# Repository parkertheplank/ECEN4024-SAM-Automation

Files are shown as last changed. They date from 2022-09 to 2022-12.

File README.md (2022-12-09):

# ECEN4024-SAM-Automation

## A fully functional program which automates the Super Air Meter, which is a quality control device for concrete, by measuring air volume and distribution. 

## Navigating the files

This repo has many folders. For the critical files and folders there will be additional READMEs. Those will be the most important to read. Here's a short explanation of the folders and files present.

 * masterSAM - The most important folder. This holds the fully functional automated program for the Arduino c/c++ IDE.
 * SAM-KICAD-Schematic - This is an electrical schematic of our automated device. 
 * SAM-MATLAB-Transducer-Calibration - Code we used to make lines of best fit to match the SAM gauge psi readings
 * SAM-Previous teams LCD - LCD code from team previous to Fall2022
 * SAM-Unit Test an assortment of unit tests we used before transitioning to our main file.

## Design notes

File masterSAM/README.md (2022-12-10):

# masterSAM

## Arduino IDE C/C++ Program which runs our device which automates the Super Air Meter Test

## Navigating the files
There are six different .ino files in this folder
* masterSAM.ino - The main file containing the core program and control loop. Open this file and the others should populate as tabs
* air.ino - Functions for air bleeding, pressurization, and air reading 
* testFunctions.ino - Several test functions that can replace mainSAM() in loop() to test various functions
* userInterface.ino - Functions for the buttons, data storage and LCD screen
* mechanical.ino - Functions for the tilt mechanism and vibrator
* water.ino - Functions for the setup and control of the water pump, intake, and outake valves.

## Running The Code
These six files must be located within a folder named 'masterSam' open masterSam.ino in the arduino IDE and other files should populate as tabs. Compile and download the masterSAM file. 

On the device itself, turn on battery power then plug USB cable in to download new changes in code. Then unplug before you turn off the switch. If you don't do it in this order it can bug out the LCD screen but no serious issue. Otherwise just turn on power switch and press start.

## Editing the Code
Always fetch origin and pull any changes before edititing, and/or create your own branch

## Outstanding Issues/Bugs
Recommendations
* Consider using micros()/millis() or some other timing module instead of the vanilla delay(). Delay() is blocking. Also millis() could be useful in measuring update rate of psi by data dumping sys time paired with psi reading and average
* Play with different lines of best fit from our MATLAB data. Implement these equations in the airRead() function
* Implement tare button - Could be an interupt which simply sets an offset float to current air reading. airRead() then would subtract this offset from equation. We were able to get .01 psi accuracy but offset error would occur between days.
* Implement some sort of reset function which will tilt back and depressurize

Bugs
* Both interupts can be triggered by relays causing noise in wire. Code currently handles this but could cause issues

Issues
* Data storage functions and variables are present but not fully implemented
* Several of the test functions require more changes to the program than simply swapping them for mainSAM() or are incomplete
* Issues could occur if proram is stopped (power switch turned off) midway through program. Some way of handling this case and running a reset funciton is needed.

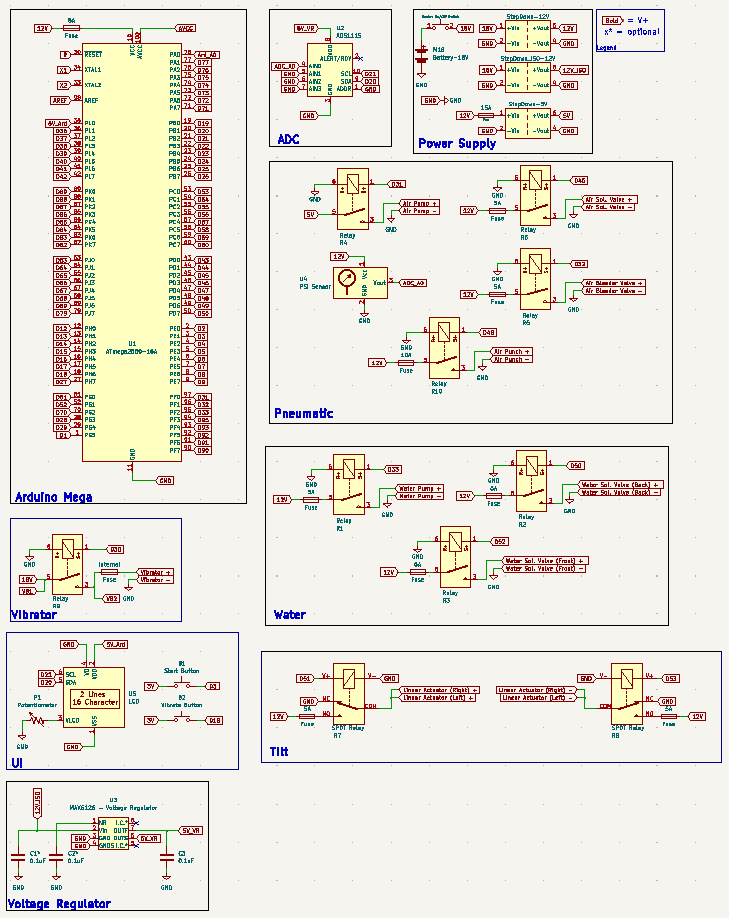
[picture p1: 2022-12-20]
ASAM_Schematic_Updated/ASAM_Schematic_Updated.PNG

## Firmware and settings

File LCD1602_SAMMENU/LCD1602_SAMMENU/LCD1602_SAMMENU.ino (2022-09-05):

#include <LiquidCrystal.h>
#include "LiquidMenu.h"
#include <EEPROM.h>
#include "Button.h"

// Pin mapping for the display
LiquidCrystal lcd(12,11,5,4,3,2);

// Button objects instantiation
Button up(8, true);//previous screen
Button down(9, true);//next screen
Button select(10, true);
Button enter(7, true);

// The analog reading sample period in seconds.
// It is later overwritten by it's EEPROM value.
unsigned short sample_period = 1;

int i=1;

int keyVal;
int P1avg=0;
int P2avg=0;
int P3avg=0;
int P4avg=0;
int P1avgtest=0;
int P2avgtest=0;
int P3avgtest=0;
int P4avgtest=0;

enum FunctionTypes { ENTER = 1,BACK = 2,};

LiquidLine KEYVAL(0,0,keyVal);

LiquidLine goback_main(13,1,"BA");
LiquidLine goback_calib(13,1,"BA");
LiquidLine goback_view(13,1,"BA");
LiquidLine goback_start(13,0, "BA");

//LiquidLine enter_start(13,0,"EN");

LiquidLine test(0, 0, "1.TEST ");
LiquidLine calib(0, 1, "2.CALIB");
LiquidLine reset(8, 0, "3.RESET");
LiquidLine light(8, 1, "4.LIGHT");
LiquidScreen screen_main(test, calib, reset, light);
LiquidMenu menu_main(lcd, screen_main);

LiquidLine sam(0, 0, "->SAM");
LiquidLine typeb(0, 1, "->TYPEB");
LiquidScreen screen_test(sam, typeb, goback_main);
LiquidMenu menu_test(lcd, screen_test);

LiquidLine start(0, 0, "->START:");
LiquidLine view(0, 1, "->VIEW:");
LiquidScreen screen_calib(start,view, goback_main);
LiquidMenu menu_calib(lcd, screen_calib);

char*  showhint="PRESS";
LiquidLine hint(0,1,showhint);
LiquidScreen screen_hint( hint,  KEYVAL);
LiquidMenu menu_hint(lcd, screen_hint);

LiquidLine cnfrm(0, 0, "->CNFRM:");
LiquidLine cancl(0, 1, "->CANCL:");
LiquidScreen screen_reset(cnfrm,cancl, goback_main);
LiquidMenu menu_reset(lcd, screen_reset);

LiquidLine off(0, 0, "->OFF:");
LiquidLine on(0, 1, "->ON:");
LiquidScreen screen_light1(off,on, goback_main);
LiquidLine Press(0, 0, "->PRESS:");
LiquidLine T20min(0, 1, "->20MIN:");
LiquidScreen screen_light2(Press,T20min, goback_main);
LiquidLine T5min(0, 0, "->5MIN:");
LiquidLine T1min(0, 1, "->1MIN:");
LiquidScreen screen_light3(T5min,T1min, goback_main);
LiquidMenu menu_light(lcd, screen_light1, screen_light2, screen_light3);

LiquidLine p1a(0, 0, "->P1-A:",P1avg);
LiquidLine p2a(0, 1, "->P2-A:",P2avg);
LiquidScreen screen_view1(p1a,p2a, goback_calib);
LiquidLine p3a(0, 0, "->P3-A:",P3avg);
LiquidLine p4a(0, 1, "->P4-A:",P4avg);
LiquidScreen screen_view2(p3a,p4a, goback_calib);
LiquidLine vtop(0, 0, "->VTOP:");
LiquidLine vbowl(0, 1, "->VBOWL:");
LiquidScreen screen_view3(vtop,vbowl, goback_calib);
LiquidMenu menu_view(lcd, screen_view1, screen_view2, screen_view3);

LiquidLine recal(0, 0, "->RECAL:");
LiquidScreen screen_vbowl(recal, goback_view);
LiquidMenu menu_vbowl(lcd, screen_vbowl);

LiquidSystem menu_system(menu_main, menu_test, menu_calib,menu_reset);

void buttonsCheck() {
  if (up.check() == LOW) {
    menu_system.previous_screen();
  }
  if (down.check() == LOW) {
    menu_system.next_screen();
  }
   if (select.check() == LOW) {
   menu_system.switch_focus();
  }
  if (enter.check() == LOW) {
    menu_system.call_function(ENTER);
  }
  return;
}

void screenshowcontrol(){
   static unsigned long lastMillis_sample01 = 0;
   keyVal= analogRead(A0);
   if (millis() - lastMillis_sample01 > (sample_period * 200)) {
      lastMillis_sample01 = millis(); 
      menu_system.update();}
   return;
}

void gobackto_menu_main() {
  menu_system.change_menu(menu_main);
  return;
}
void goto_menu_test() {
  menu_system.change_menu(menu_test);
  return;
}
void goto_menu_calib() {
  menu_system.change_menu(menu_calib);
  return;
}
void goto_menu_reset() {
  menu_system.change_menu(menu_reset);
  return;
}
void goto_menu_light() {
  menu_system.change_menu(menu_light);
  return;
}
void goto_menu_view() {
  menu_system.change_menu(menu_view);
  return;
}
void goto_menu_vbowl() {
  menu_system.change_menu(menu_vbowl);
  return;
}

void goto_menu_start(){ 
 while(enter.check() == HIGH){
    menu_system.change_menu(menu_hint);
    long lastMillis_test =millis();
    int t=0;
     while (t<8800){
        t=millis()-lastMillis_test;
       // keyVal= analogRead(A0);
        if (t < 800) {  
          showhint=(char*)"          PRESS/"; 
          screenshowcontrol();}
        if (t > 800 && t< 1600) { 
          showhint=(char*)"          ENTER/"; 
          screenshowcontrol();}
        if (t > 1600 && t< 2400) { 
          showhint=(char*)"             TO/"; 
          screenshowcontrol();}
        if (t > 2400 && t< 3200) { 
          showhint=(char*)"         BEGAIN/";
         screenshowcontrol();}
        if (t > 3200 && t< 4000) { 
          showhint=(char*)"            SAM/";
          screenshowcontrol();}
        if (t > 4000 && t< 4800) { 
          showhint=(char*)"          CALIB/";
          screenshowcontrol();}
        if (t > 4800 && t< 5600) { 
          showhint=(char*)"             OR/";
         screenshowcontrol();}
        if (t > 5600 && t< 6400) { 
          showhint=(char*)"           HOLD/";
          screenshowcontrol();}
        if (t > 6400 && t< 7200) { 
          showhint=(char*)"           MENU/";
          screenshowcontrol();}
        if (t > 7200 && t< 8000) { 
          showhint=(char*)"             TO/";
          screenshowcontrol();}
        if (t > 8000 && t< 8800) {
          showhint=(char*)"           ABORT";
          screenshowcontrol();}
        if (enter.check() == LOW) {goto_menu_startEnter(); return;}}}
 }

void goto_menu_startEnter(){
  goto_menu_apply1450();
  goto_menu_startEnterEnter();
  return;
}

void goto_menu_apply1450(){ 
  while(enter.check() == HIGH){   
    menu_system.change_menu(menu_hint);
    long lastMillis_test =millis();
    int t=0;
     while (t<4800){
        t=millis()-lastMillis_test;
        if (t < 800) {  
          showhint=(char*)"          APPLY/"; 
          screenshowcontrol();}
        if (t > 800 && t< 1600) { 
          showhint=(char*)"          14.50/"; 
          screenshowcontrol();}
        if (t > 1600 && t< 2400) { 
          showhint=(char*)"            PSI/"; 
          screenshowcontrol();}
        if (t > 2400 && t< 3200) { 
          showhint=(char*)"           THEN/";
          screenshowcontrol();}
        if (t > 3200 && t< 4000) { 
          showhint=(char*)"          PRESS/";
          screenshowcontrol();}
        if (t > 4000 && t< 4800) { 
          showhint=(char*)"           ENTER";
          screenshowcontrol();}
        if (enter.check()==LOW){return;}
 }}}
 
void goto_menu_startEnterEnter(){ 
  menu_system.change_menu(menu_hint); 
  /****************************************************************************************************
   * capture five measurements while flashing “READ”
  *****************************************************************************************************/
  long lastMillis_test =millis();
  int t=0;
  while (t<7100){ 
    t=millis()-lastMillis_test;
    if (t < 5000) {
      int a=t/400;
      if ((a%2)!=0){  
        showhint=(char*)"            READ";  
        screenshowcontrol();}
        else {
          showhint=(char*)" ";  
          screenshowcontrol();}}
     if (t > 5000 && t< 7000) { 
         if(keyVal>800){
            showhint=(char*)"      NOT STABLE"; 
            screenshowcontrol();}
         else{
          if(keyVal>200 && keyVal<600){               
              showhint=(char*)"              OK"; 
              screenshowcontrol();}
          if(keyVal<200){
              showhint=(char*)"             LOW"; 
              screenshowcontrol();}
           if(keyVal>600 && keyVal<800){
              showhint=(char*)"            HIGH"; 
              screenshowcontrol();}
            }}
     if (t > 7000 && t <7100){
         if(keyVal<200 || keyVal>600 ){goto_menu_startEnter(); return;}
         if(keyVal>200 && keyVal<600){goto_menu_startEEOK();return;}
}}}

void goto_menu_startEEOK(){
    goto_menu_holdhint();
    goto_menu_holdcount();
    goto_menu_startEEEnter();
    return;
 }

void goto_menu_holdhint(){  
  while(enter.check()==HIGH){
    menu_system.change_menu(menu_hint);
    long lastMillis_test =millis();
    int t=0;
    while (t<4000){
        t=millis()-lastMillis_test;
        if (t < 800) { 
              showhint=(char*)"           HOLD/"; 
              screenshowcontrol();}
        if (t > 800 && t< 1600) { 
              showhint=(char*)"          LEVER/"; 
              screenshowcontrol();}
        if (t > 1600 && t< 2400) { 
              showhint=(char*)"           THEN/";
              screenshowcontrol();}
        if (t > 2400 && t< 3200) { 
               showhint=(char*)"          PRESS/";
              screenshowcontrol();}
        if (t > 3200 && t< 4000) { 
              showhint=(char*)"           ENTER";
              screenshowcontrol();}
        if (enter.check() == LOW) {
              return;}
 }}}

void goto_menu_holdhithint(){  
  while(enter.check()==HIGH){
    menu_system.change_menu(menu_hint);
    long lastMillis_test =millis();
    int t=0;
    while (t<4800){
        t=millis()-lastMillis_test;
        if (t < 800) { 
              showhint=(char*)"           HOLD/"; 
              screenshowcontrol();}
        if (t > 800 && t< 1600) { 
              showhint=(char*)"          LEVER/"; 
              screenshowcontrol();}
        if (t > 1600 && t< 2400) { 
              showhint=(char*)"            HIT/";
              screenshowcontrol();}
        if (t > 2400 && t< 3200) { 
              showhint=(char*)"           THEN/";
              screenshowcontrol();}
        if (t > 3200 && t< 4000) { 
              showhint=(char*)"          PRESS/";
              screenshowcontrol();}
        if (t > 4000 && t< 4800) { 
              showhint=(char*)"           ENTER";
              screenshowcontrol();}
        if (enter.check() == LOW) {
              return;}
 }}}

void goto_menu_holdcount(){
    menu_system.change_menu(menu_hint);
    long lastMillis_test =millis();
    int t=0;
    while (t<8100){
        t=millis()-lastMillis_test; 
        if ( t< 800) { 
              showhint=(char*)"           HOLD9";
              screenshowcontrol();}
        if (t > 800 && t< 1600) { 
              showhint=(char*)"           HOLD8";
              screenshowcontrol();}
        if (t > 1600 && t< 2400) { 
              showhint=(char*)"           HOLD7";
              screenshowcontrol();}
        if (t > 2400 && t< 3200) { 
              showhint=(char*)"           HOLD6";
              screenshowcontrol();}
        if (t > 3200 && t< 4000) { 
              showhint=(char*)"           HOLD5";
              screenshowcontrol();}
        if (t > 4000 && t< 4800) { 
              showhint=(char*)"           HOLD4";
              screenshowcontrol();}
        if (t > 4800 && t< 5600) { 
              showhint=(char*)"           HOLD3";
              screenshowcontrol();}
        if (t > 5600 && t< 6400) { 
              showhint=(char*)"           HOLD2";
              screenshowcontrol();}
        if (t > 6400 && t< 7200) { 
              showhint=(char*)"           HOLD1";
              screenshowcontrol();}
        if (t > 7200 && t< 8000) { 
              showhint=(char*)"           HOLD0";
              screenshowcontrol();}
}}

void goto_menu_startEEEnter(){
    goto_menu_readhint();
    if(keyVal>800){goto_Error();return;}
    else{
        P1avgtest=keyVal;
        goto_menu_OKhint();
        goto_menu_startEEEEnter();
        return;
        }
}

void goto_menu_readhint(){
  menu_system.change_menu(menu_hint);
  long lastMillis_test =millis();
  int t=0;
  while (t<5000){ 
    t=millis()-lastMillis_test;
    int a=t/400;
    if ((a%2)!=0){  
        showhint=(char*)"            READ";  
        screenshowcontrol();}
    else {
        showhint=(char*)" ";  
        screenshowcontrol();}}}

void goto_menu_OKhint(){
  menu_system.change_menu(menu_hint);
  long lastMillis_test =millis();
  int t=0;
  while (t<2000){ 
    t=millis()-lastMillis_test;
    showhint=(char*)"              OK";  
    screenshowcontrol();
   }
}

void goto_Error(){ 
  while(enter.check() == HIGH){   
    menu_system.change_menu(menu_hint);
    long lastMillis_test =millis();
    int t=0;
    while (t<5600){
        t=millis()-lastMillis_test;
        if (t < 800) {  
          showhint=(char*)"          ERROR/"; 
          screenshowcontrol();}
        if (t > 800 && t< 1600) { 
          showhint=(char*)"            NOT/"; 
          screenshowcontrol();}
        if (t > 1600 && t< 2400) { 
          showhint=(char*)"         STABLE/"; 
          screenshowcontrol();}
        if (t > 2400 && t< 3200) { 
          showhint=(char*)"          PRESS/";
          screenshowcontrol();}
        if (t > 3200 && t< 4000) { 
          showhint=(char*)"          ENTER/";
         screenshowcontrol();}
        if (t > 4000 && t< 4800) { 
          showhint=(char*)"             TO/";
          screenshowcontrol();}
        if (t > 4800 && t< 5600) { 
          showhint=(char*)"            EXIT";
          screenshowcontrol();}
        if (enter.check() == LOW) {gobackto_menu_main();return;}
 }}}

void goto_menu_startEEEEnter(){
  goto_menu_apply3000();
  goto_menu_P2Enter();
  return;
}

void goto_menu_apply3000(){ 
  while(enter.check() == HIGH){   
    menu_system.change_menu(menu_hint);
    long lastMillis_test =millis();
    int t=0;
     while (t<4800){
       // keyVal= analogRead(A0);
        t=millis()-lastMillis_test;
        if (t < 800) {  
          showhint=(char*)"          APPLY/"; 
          screenshowcontrol();}
        if (t > 800 && t< 1600) { 
          showhint=(char*)"          30.00/"; 
         screenshowcontrol();}
        if (t > 1600 && t< 2400) { 
          showhint=(char*)"            PSI/"; 
          screenshowcontrol();}
        if (t > 2400 && t< 3200) { 
          showhint=(char*)"           THEN/";
          screenshowcontrol();}
        if (t > 3200 && t< 4000) { 
          showhint=(char*)"          PRESS/";
         screenshowcontrol();}
        if (t > 4000 && t< 4800) { 
          showhint=(char*)"           ENTER";
          screenshowcontrol();}
        if (enter.check() == LOW) { return;}
 }}}

void goto_menu_P2Enter(){ 
  menu_system.change_menu(menu_hint); 
  /****************************************************************************************************
   * capture five measurements while flashing “READ”
  *****************************************************************************************************/
  long lastMillis_test =millis();
  int t=0;
  while (t<7100){ 
    t=millis()-lastMillis_test;
    if (t < 5000) {
      int a=t/400;
      if ((a%2)!=0){  
        showhint=(char*)"            READ";  
        screenshowcontrol();}
      else {
        showhint=(char*)" ";  
        screenshowcontrol();}}
    if (t > 5000 && t< 7000) { 
         if(keyVal>200 && keyVal<600){               
            showhint=(char*)"              OK"; 
            screenshowcontrol();}
         if(keyVal<200){
            showhint=(char*)"             LOW"; 
            screenshowcontrol();}
         if(keyVal>600 && keyVal<800){
            showhint=(char*)"            HIGH"; 
            screenshowcontrol();}
            }
     if (t > 7000 && t <7100){
         if(keyVal<200 || keyVal>600){goto_menu_startEEEEnter();return;}
         if(keyVal>200 && keyVal<600){goto_menu_P2EOK();return;}
}}}

void goto_menu_P2EOK(){
  goto_menu_holdhint();
  goto_menu_holdcount();
  goto_menu_P2EEnter();
  return;
}

void goto_menu_P2EEnter(){
  goto_menu_readhint();
  if(keyVal>800){goto_Error();return;}
  else{
        P2avgtest=keyVal;
        goto_menu_OKhint();
        goto_menu_P2EEEnter();return;
        }
}

void goto_menu_P2EEEnter(){
  goto_menu_apply4500();
  goto_menu_P3Enter();
  return;
}
         
void goto_menu_apply4500(){
 while(enter.check() == HIGH){   
    menu_system.change_menu(menu_hint);
    long lastMillis_test =millis();
    int t=0;
     while (t<4800){
        t=millis()-lastMillis_test;
        if (t < 800) {  
          showhint=(char*)"          APPLY/"; 
          screenshowcontrol();}
        if (t > 800 && t< 1600) { 
          showhint=(char*)"          45.00/"; 
          screenshowcontrol();}
        if (t > 1600 && t< 2400) { 
          showhint=(char*)"            PSI/"; 
          screenshowcontrol();}
        if (t > 2400 && t< 3200) { 
          showhint=(char*)"           THEN/";
          screenshowcontrol();}
        if (t > 3200 && t< 4000) { 
          showhint=(char*)"          PRESS/";
          screenshowcontrol();}
        if (t > 4000 && t< 4800) { 
          showhint=(char*)"           ENTER";
          screenshowcontrol();}
        if (enter.check() == LOW) {return;}
 }}}

 void goto_menu_P3Enter(){
  menu_system.change_menu(menu_hint); 
  /****************************************************************************************************
   * capture five measurements while flashing “READ”
  *****************************************************************************************************/
  long lastMillis_test =millis();
  int t=0;
  while (t<7100){ 
    t=millis()-lastMillis_test;
    if (t < 5000) {
      int a=t/400;
      if ((a%2)!=0){  
        showhint=(char*)"            READ";  
        screenshowcontrol();}
      else {
        showhint=(char*)" ";  
        screenshowcontrol();}}
    if (t > 5000 && t< 7000) { 
         if(keyVal>200 && keyVal<600){               
            showhint=(char*)"              OK"; 
            screenshowcontrol();}
         if(keyVal<200){
            showhint=(char*)"             LOW"; 
            screenshowcontrol();}
         if(keyVal>600 && keyVal<800){
            showhint=(char*)"            HIGH"; 
            screenshowcontrol();}
            }
     if (t > 7000 && t <7100){
         if(keyVal<200 || keyVal>600){goto_menu_P2EEEnter();return;}
         if(keyVal>200 && keyVal<600){goto_menu_P3EOK();return;}
         }}}

void goto_menu_P3EOK(){
  goto_menu_holdhint();
  goto_menu_holdcount();
  goto_menu_P3EEnter();
  return;
}

void goto_menu_P3EEnter(){
    goto_menu_readhint();
    if(keyVal>800){goto_Error();return;}
    else{
        P3avgtest=keyVal;
        // This is where the user removes the lid and places a calibration can in the chamber.
        goto_menu_OKhint();
        goto_menu_P3EEEnter();
        return;
        }
    }

void goto_menu_P3EEEnter(){
  // This is where the user removes the lid and places a calibration can in the chamber.
   while(enter.check() == HIGH){   
    menu_system.change_menu(menu_hint);
    long lastMillis_test =millis();
    int t=0;
     while (t<5600){
        t=millis()-lastMillis_test;
        if (t < 800) {  
          showhint=(char*)"          PURGE/"; 
          screenshowcontrol();}
        if (t > 800 && t< 1600) { 
          showhint=(char*)"            ADD/"; 
          screenshowcontrol();}
        if (t > 1600 && t< 2400) { 
          showhint=(char*)"            ONE/"; 
          screenshowcontrol();}
        if (t > 2400 && t< 3200) { 
          showhint=(char*)"            CAN/";
          screenshowcontrol();}
        if (t > 3200 && t< 4000) { 
          showhint=(char*)"           THEN/";
          screenshowcontrol();}
        if (t > 4000 && t< 4800) { 
          showhint=(char*)"           PRESS";
          screenshowcontrol();}
        if (t > 4800 && t< 5600) { 
          showhint=(char*)"           ENTER";
          screenshowcontrol();}
        if (enter.check() == LOW) {goto_menu_P3EEEEnter();return;/*if select button has been poshed,then stop showing the hint.*/}
 }}}

void goto_menu_P3EEEEnter(){
   goto_menu_apply1450();
   goto_menu_P4Enter();
   return;
 }

void goto_menu_P4Enter(){
  menu_system.change_menu(menu_hint); 
  /****************************************************************************************************
   * capture five measurements while flashing “READ”
  *****************************************************************************************************/
  long lastMillis_test =millis();
  int t=0;
  while (t<7100){ 
    t=millis()-lastMillis_test;
    if (t < 5000) {
      int a=t/400;
      if ((a%2)!=0){  
        showhint=(char*)"            READ";  
        screenshowcontrol();}
      else {
        showhint=(char*)" ";  
        screenshowcontrol();}}
    if (t > 5000 && t< 7000) { 
         if(keyVal>200 && keyVal<600){               
            showhint=(char*)"              OK"; 
            screenshowcontrol();}
         if(keyVal<200){
            showhint=(char*)"             LOW"; 
            screenshowcontrol();}
         if(keyVal>600 && keyVal<800){
            showhint=(char*)"            HIGH"; 
            screenshowcontrol();}
            }
     if (t > 7000 && t <7100){
         if(keyVal<200 || keyVal>600){goto_menu_P3EEEEnter();return;}
         if(keyVal>200 && keyVal<600){goto_menu_P4EOK();return;}
}}}

void goto_menu_P4EOK(){
  goto_menu_holdhint();
  goto_menu_holdcount();
  goto_menu_P4EEnter();
  return;
}

void goto_menu_P4EEnter(){
  goto_menu_readhint();
  if(keyVal>800){goto_Error();return;}
  else{
        P4avgtest=keyVal;
        // PressCorr = 7.51 – P4avg 
        // Note: This finds the correction to the equilibrium pressure to force meter to read 4.9% air +/-0.1% with a Pro Cali Can
        goto_menu_OKhint();
        goto_menu_P4EEEnter();return;}
}
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
void loop() {
  buttonsCheck();
  keyVal= analogRead(A0);
  Serial.print("keyVal:");
  Serial.println(keyVal);
  screenshowcontrol();}

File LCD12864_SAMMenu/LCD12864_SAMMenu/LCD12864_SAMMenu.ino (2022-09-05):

/*

  Menu.pde
  
  Simple Menu Selection

  >>> Before compiling: Please remove comment from the constructor of the 
  >>> connected graphics display (see below).
  
  Universal 8bit Graphics Library, https://github.com/olikraus/u8glib/
  
  Copyright (c) 2012, olikraus@gmail.com
  All rights reserved.

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
  THIS SOFTWARE IS PROVIDED BY THE COPYRIGHT HOLDERS AND 
  CONTRIBUTORS "AS IS" AND ANY EXPRESS OR IMPLIED WARRANTIES, 
  INCLUDING, BUT NOT LIMITED TO, THE IMPLIED WARRANTIES OF 
  MERCHANTABILITY AND FITNESS FOR A PARTICULAR PURPOSE ARE 
  DISCLAIMED. IN NO EVENT SHALL THE COPYRIGHT HOLDER OR 
  CONTRIBUTORS BE LIABLE FOR ANY DIRECT, INDIRECT, INCIDENTAL, 
  SPECIAL, EXEMPLARY, OR CONSEQUENTIAL DAMAGES (INCLUDING, BUT 
  NOT LIMITED TO, PROCUREMENT OF SUBSTITUTE GOODS OR SERVICES; 
  LOSS OF USE, DATA, OR PROFITS; OR BUSINESS INTERRUPTION) HOWEVER 
  CAUSED AND ON ANY THEORY OF LIABILITY, WHETHER IN CONTRACT, 
  STRICT LIABILITY, OR TORT (INCLUDING NEGLIGENCE OR OTHERWISE) 
  ARISING IN ANY WAY OUT OF THE USE OF THIS SOFTWARE, EVEN IF 
  ADVISED OF THE POSSIBILITY OF SUCH DAMAGE.  
  

*/


#include "U8glib.h"
#include "Button.h"
#include <stdio.h>

U8GLIB_KS0108_128 u8g(8, 9, 10, 11, 4, 5, 6, 7, 18, 14, 15, 17, 16); 		// 8Bit Com: D0..D7: 8,9,10,11,4,5,6,7 en=18, cs1=14, cs2=15,di=17,rw=16

float error = 5.00;
float minval = 13.00;
float maxval = 50.00;
float Vc = 1;
float Vbowl = 1;
float Presscorr = 1.00;

Button up(22, true);//previous screen
Button down(26, true);//next screen
Button enter(30, true);
Button back(34, true);

float measure[5];
float meas_error[5];
float P1avg,P2avg,P3avg,P4avg;
char *PoiP1avg = "####";
char *PoiP2avg = "####";
char *PoiP3avg = "####";
char *PoiP4avg = "####";
char strP1avg[10],strP2avg[10], strP3avg[10], strP4avg[10];//item number must be 10, otherwise there'll be garbled after transfer into string
float P1meas, P2meas, P3meas, P4meas, P5meas, P6meas;
char strP1meas[10], strP2meas[10], strP3meas[10], strP4meas[10], strP5meas[10], strP6meas[10];
float air;
char strair[10];
char *Poiair = "####";
float air_T;
char strair_T[10];
char *Poiair_T = "####";
float SAM;
char strSAM[10];
char *PoiSAM = "####";
float P1measmod;
float pressure;
char strpressure[10];
char *Poipressure;


char *menu_main[6] = { "1.TEST ", "2.CALIB", "3.RESET", "4.LIGHT","","Zero"};
char *menu_test[2] = {"1.SAM", "2.TYPEB"};
char *menu_calib[2] = {"1.START", "2.VIEW"};
char *menu_reset[2] = {"1.CNFRM", "2.CANCL"};
char *menu_light[6] = {"OFF", "ON", "PRESS", "20MIN", "5MIN", "1MIN"};
char *menu_view[10] = {"P1-A:", "P2-A:", "P3-A:", "P4-A:", "VTOP", "VBOWL",PoiP1avg,PoiP2avg,PoiP3avg,PoiP4avg};
char *menu_vbowl[1] = {"RECAL"};
char *calstart_e[4] = {"","PRESS ENTER TO BEGIN", "SAM CALIB OR PRESS", "BACK TO ABORT"};
char *PSI_145[12] = {"", "", "APPLY 14.50 PSI THEN", "PRESS ENTER","","Pressure:","","","","","",""};
char *PSI_OK[12] = {"","","HOLD LEVER THEN","PRESS ENTER","","Pressure:","","","","","",""};
char *error_message[4] = {"","","ERROR! NOT STABLE!","PRESS ENTER TO EXIT"};
char *PSI_30[12] = {"", "", "APPLY 30.00 PSI THEN", "PRESS ENTER","","Pressure:","","","","","",""};
char *PSI_45[12] = {"", "", "APPLY 45.00 PSI THEN", "PRESS ENTER","","Pressure:","","","","","",""};
char *calib_can[4] = {"","","PURGE ADD ONE CAN THEN", "PRESS ENTER"};
char *calib_done[4] = {"","SAM CALIB DONE","PRESS ENTER TO SAVE /","PRESS BACK TO ABORT"};
char *SAM_e[4] = {"","PRESS ENTER TO BEGIN", "SAM TEST OR PRESS", "BACK TO ABORT"};
char *SAMPSI_OK[12] = {"","","HOLD LEVER HIT THEN","PRESS ENTER","","Pressure:","","","","","",""};
char *SAMP1_right[4] = {"","","PRESS ENTER TO VIEW","AIR VALUE"};
char *view_airval[6] = {"","AIR VALUE:","PRESS ENTER OR","PRESS BACK TO ABORT","",Poiair};
char *SAM_RERUN[4] = {"","","PURGE AND RERUN","THEN PRESS ENTER"};
char *_done[4] = {"","DONE","PRESS ENTER TO VIEW /","OR PRESS BACK TO EXIT"};
char *air_SAM[10] = {"","","AIR:","SAM:","","ABORT","","",Poiair,PoiSAM};
char *hold_count[10] = {"HOLD9","HOLD8","HOLD7","HOLD6","HOLD5","HOLD4","HOLD3","HOLD2","HOLD1","HOLD0"};
char *typeb_e[4] = {"","PRESS ENTER TO BEGIN","TYPEB TEST OR PRESS","BACK TO ABORT"};
char *air_val[8] = {"","","AIR:","","ABORT","","",Poiair_T};

//////////////////////////////////////////////////////////////////////////////////////////////
void goto_addpoint(char *a){
  a[4] = a[3];
  a[3] = a[2];
  a[2] = '.';
}
///////////////////////////// basic set && get the value of h and w   
uint8_t h;
u8g_uint_t w;  
void basicset(){  
  u8g.setFont(u8g_font_6x10);
  u8g.setFontRefHeightText();
  u8g.setFontPosTop();
  
  h = u8g.getFontAscent()-u8g.getFontDescent();// h=9
  w = u8g.getWidth();//w=128
  //Serial.println(h);
  //Serial.println(w);
}
//////////////////////////////////////////////////////////////////////////////////////////////////////////
void getpressure(){
  pressure = analogRead(A8);
  int newF1 = round(pressure*100);
  sprintf(strpressure,"%03d",newF1);
  goto_addpoint(strpressure);
  Poipressure = &strpressure[0];
}
//////////////////////////////////////////////////////////////////////////////////////////////////////////
void MENU_SHOW(int MENU_ITEMS01, int menu_current, int MENU_ITEMS02, int val_start_posi,  char *menu_content[]){
  u8g.firstPage();
  do{ uint8_t i;
      for( i = 0; i < MENU_ITEMS01; i++ ) {
        u8g.setDefaultForegroundColor();    
        if ( i == menu_current ) {
          u8g.drawBox(0, i*h, 64, h);
          u8g.setDefaultBackgroundColor();
        }    
        u8g.drawStr(1, i*h, menu_content[i]);
      }
      for( i = 0; i < MENU_ITEMS02; i++ ) {
        u8g.setDefaultForegroundColor();        
        u8g.drawStr(val_start_posi, i*h, menu_content[i+MENU_ITEMS01]);
      }
  }while(u8g.nextPage());  
}

/////////////////////////////////////////////////////////////////////////////////////////////////////
void DYNAMIC_SHOW(int x, int y, float timespan, char *showcontent, bool showpre){
  uint8_t draw_state = 0;
  long lastMillis_test =millis();
  int t=0;
  while (t<(timespan*1000)){ 
    t=millis()-lastMillis_test;
    u8g.firstPage();  
    do {
        switch(draw_state >> 3) { //右移运算符 ">>" 将第一个操作数向右移动第二个操作数指定的位数。
          case 0: u8g.drawStr( x, y, showcontent);
          case 1: u8g.drawStr( 0, 0, "");}

        if (showpre == 1){
          u8g.drawStr(1,45,"Pressure:");
          getpressure();  
          u8g.drawStr(61,45,Poipressure); 
        }
              
       } while( u8g.nextPage() );  
    draw_state++;
    if ( draw_state >= 15*1 ){draw_state = 0;}
  }  
}
/////////////////////////////////////////////////////////////////////////////////////////////////////////
void goto_main0(void) {
  while(!(up.check()==LOW||down.check()==LOW || enter.check()==LOW)){
  MENU_SHOW(6,0,0,0,menu_main);   
  if (down.check() == LOW){goto_main1();}
  if (up.check()==LOW){goto_main4();}
  if (enter.check()==LOW){goto_test0();}
  }
}
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

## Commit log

2022-08-30 Kicad basic files
    need to import schematics for arduino etc
    [SAM-Schematic.kicad_pcb, SAM-Schematic.kicad_sch]
2022-08-30 ugly arduino footprin
    [SAM-Schematic.kicad_sch]
2022-09-01 chm first draft
    need to update relay names and may need to change arduino pins. Assumed we'd use I2C for LCD screen but we could do it the beefy pin way too
    [SAM-Schematic.kicad_sch]
2022-09-01 Cleaned up a bit
    [SAM-Schematic.kicad_sch]
2022-09-09 schematic update
    [SAM-Schematic.kicad_sch]
2022-09-26 Add files via upload
    The transducer calibration code.
2022-10-04 improve control flow, filled out functions
2022-10-07 adc cal
2022-10-28 Completed control flow for whole process
2022-10-28 Button interupts
2022-11-15 Update air.ino
    calibration
2022-11-16 relay psi interefence test
2022-11-18 vibrate interrupt
2022-12-01 control flow changes
2022-12-09 Revert "nbbbb"
    This reverts commit d28bcbb240e023eece0f38c669b84fc6fab9ba39.
    [SAM-Schematic.kicad_pcb, SAM-Schematic.kicad_sch]
2022-12-09 Add files via upload
    matlab calibration
2022-12-09 file re-organization
    [SAM-Schematic.kicad_pcb, SAM-Schematic.kicad_sch]
2022-12-20 updated schematic
    [SAM.kicad_sch]
